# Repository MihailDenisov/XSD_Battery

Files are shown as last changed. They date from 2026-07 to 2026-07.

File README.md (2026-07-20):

# XDS_Batt — аналог аккумуляторной батареи для осциллографа Owon XDS

Плата-замена штатной аккумуляторной сборки осциллографа Owon XDS: та же механическая компоновка и электрический интерфейс (10-контактный разъём), но с ёмкостью элементов увеличенной с ~2000 до 4000 мАч (Vapcell N40), удешевлённым контроллером заряда и собственной логикой автоматического отключения выходного преобразователя во время хранения — устраняет паразитный разряд оригинальной батареи (полная разрядка за 1-1.5 месяца даже при выключенном приборе).

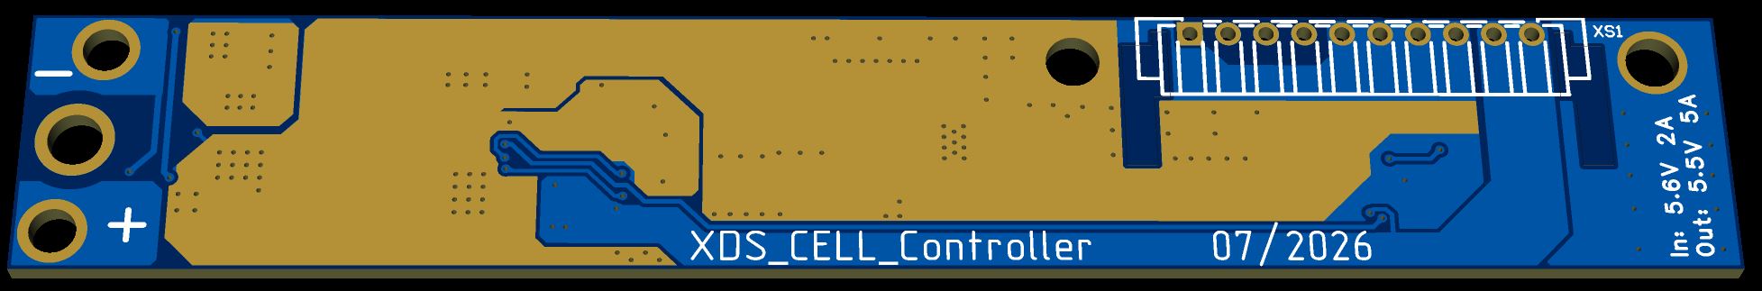
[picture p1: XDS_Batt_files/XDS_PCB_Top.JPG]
PCB top

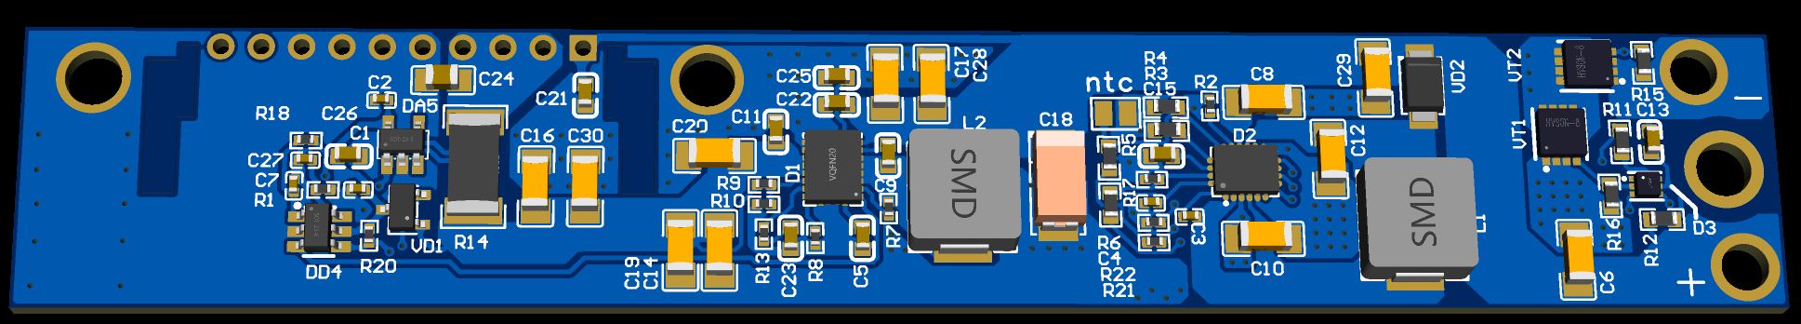
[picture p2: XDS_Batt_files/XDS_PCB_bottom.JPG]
PCB bottom


Проект платы (EasyEDA/OSHWLab): [project_svjrqlut](https://oshwlab.com/mihaildenisov/project_svjrqlut) *(ссылка станет доступна после прохождения модерации)*

Gerber-файлы для заказа платы: [XDS_Batt_Controller.zip](XDS_Batt_Controller.zip)

## Совместимость

Батарея и разъём повторяют оригинальную механику и распиновку, поэтому применимы (под одним и тем же OEM-корпусом/платформой) к следующим сериям осциллографов:

| Бренд | Серии |
|---|---|
| OWON | XDS 30xx, 31xx, 32xx, 33xx |
| АКИП | 4122/(7-12) |
| АКТАКОМ | ADS 60xx, 61xx, 62xx, 63xx |
| VERDO | SB16xx |

## Основные характеристики

| Параметр | Значение |
|---|---|
| Аккумуляторная сборка | 1S6P, Li-Ion 18650, Vapcell N40 (4000 мАч/элемент) |
| Вход заряда | 5.6 В, до 2 А |
| Выход (питание осциллографа) | 5.5 В, до 5 А |
| Автоотключение при простое | ~48 часов без нагрузки и без заряда → перевод в транспортировочный режим |
| Интерфейс | 10-контактный разъём (совместим с оригинальной батареей) |

## Архитектура платы

Полная принципиальная схема — `XDS_Batt_files/XDS_Schematic.JPG`.

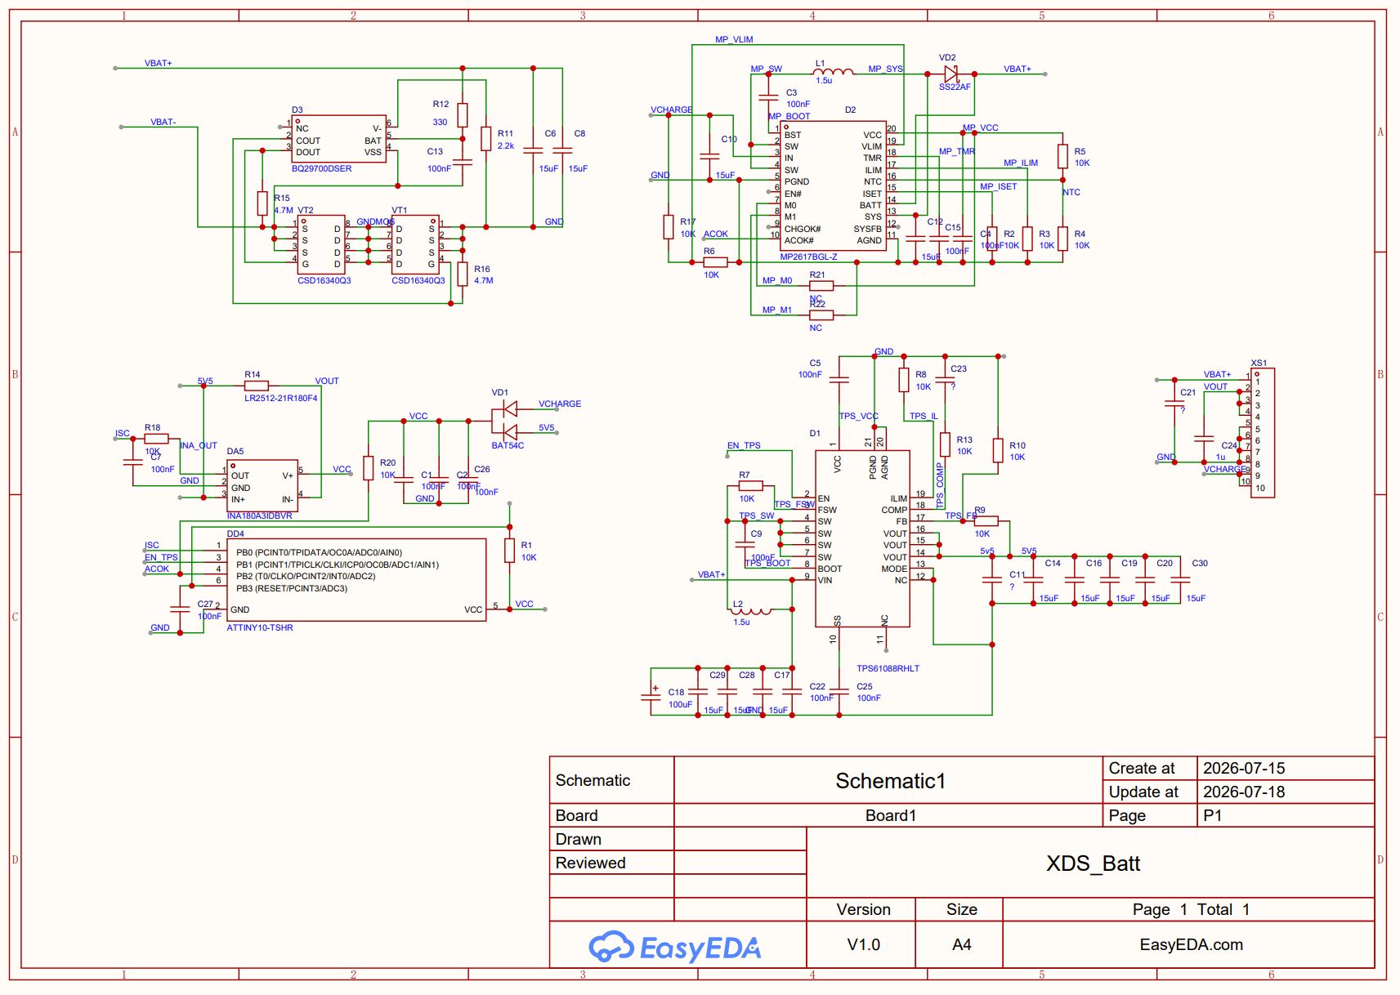
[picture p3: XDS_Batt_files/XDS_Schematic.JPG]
Schematic


### 1. Защита батареи — BQ29700 + сдвоенные N-MOSFET
Классическая схема защиты Li-Ion сборки: **BQ29700DSER** (D3) управляет двумя сдвоенными N-канальными ключами **CSD16340Q3** (VT1, VT2), включёнными последовательно в цепь VBAT- для отключения при перезаряде/переразряде/КЗ. Независима от остальной электроники платы — работает даже при полностью обесточенном контроллере.

### 2. Зарядное устройство — MP2617B
**MP2617BGL-Z** — импульсный зарядчик с автоматическим power path management:
- Входной ток ограничен ~2 А (Default Mode: M0/M1 не задействованы — R21/R22 не запаяны, что соответствует плавающим входам и заводскому лимиту тока без внешнего резистора ILIM);
- Входное напряжение ограничивается делителем на VLIM (R2-R4) — защита сетевого адаптера от просадки при перегрузке;
- Ток заряда задаётся резистором на ISET;
- Таймер безопасности — конденсатором на TMR;
- NTC-вход подключён (термоконтроль элементов при заряде);
- Статусные выходы CHGOK#/ACOK# используются платой контроллера (ACOK# — индикация наличия входного напряжения заряда для алгоритма автоотключения, см. ниже).

Выход SYS не используется как отдельная системная шина — питание повышающего преобразователя (TPS61088) берётся напрямую с VBAT+, в обход SYS, так как MP2617B не рассчитан на токи, необходимые TPS61088.

### 3. Повышающий преобразователь — TPS61088
**TPS61088RHLT** — buck-boost/boost преобразователь, формирующий выходные 5.5 В из напряжения батареи (3.0-4.2 В) для питания осциллографа. Включается/выключается по входу EN, управляемому контроллером на ATtiny10 (см. ниже) — это ключевое отличие от оригинальной батареи, где аналогичная микросхема работала постоянно и разряжала сборку даже при выключенном приборе.

### 4. Контроллер простоя — ATtiny10 + INA180A3
Узел, устраняющий паразитный разряд:

- **INA180A3IDBVR** (DA5) измеряет ток в цепи выходных 5.5 В через шунт **R14**, усиленный сигнал через RC-фильтр подаётся на вход АЦП ATtiny10 (PB0/ADC0).
- **ATtiny10** (DD4) также принимает сигнал ACOK# от зарядного устройства (PB2) и управляет входом EN преобразователя TPS61088 (PB1).
- Питание контроллера и датчика тока — через диодную сборку **BAT54C** (VD1) от входа заряда (VCHARGE) и от выхода (5V5/VOUT) — работает при наличии любого из двух источников.

**Алгоритм** (реализация — прошивка ATtiny10, Atmel Studio / avr-gcc; исходники — [ATtiny10_XDS_Power](https://github.com/MihailDenisov/XSD_Battery/tree/main/ATtiny10_XDS_Power)):
1. При появлении напряжения на входе заряда МК запускает TPS61088 (EN=1) и переходит в цикл сна с пробуждением по Watchdog каждые 8 секунд.
2. При каждом пробуждении проверяется: (а) наличие сигнала ACOK# (заряд подключён), (б) ток нагрузки выше порога (~500 мА — прибор включён).
3. Если оба условия отсутствуют — инкремент счётчика простоя; при наличии любого из них — сброс счётчика.
4. По достижении счётчиком значения, соответствующего ~48 часам непрерывного простоя, контроллер отключает TPS61088 (EN=0), обесточивая тем самым себя, датчик тока и электронику осциллографа — плата переходит в режим хранения с минимальным током утечки.
5. Выход из режима хранения — только через повторное подключение к сетевому адаптеру (появление напряжения на входе заряда).

## Разъём XS1 (совместим с оригинальной батареей)

| Контакт(ы) | Назначение |
|---|---|
| 1 | Выход для контроля уровня заряда прибором |
| 2, 3, 4 | Выход преобразователя, питание прибора 5.5 В |
| 5, 6, 7, 8 | Общий минус (GND) |
| 9, 10 | Вход от блока питания прибора для заряда |

Схема — `XDS_Batt_files/XDS_Schematic.JPG` (XS1).

## Корпус (3D-модель для печати)

Корпус состоит из двух частей: основание и крышка-слайдер (вставляется по пазам, фиксируется 1 винтом).

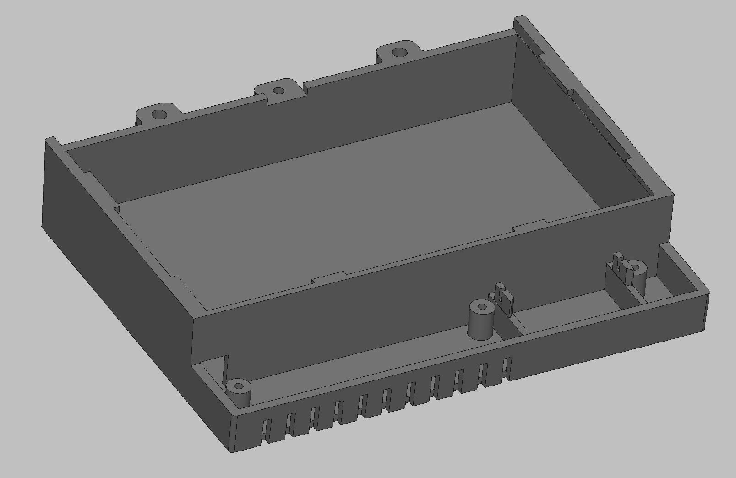
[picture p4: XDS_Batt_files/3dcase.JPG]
Основание корпуса

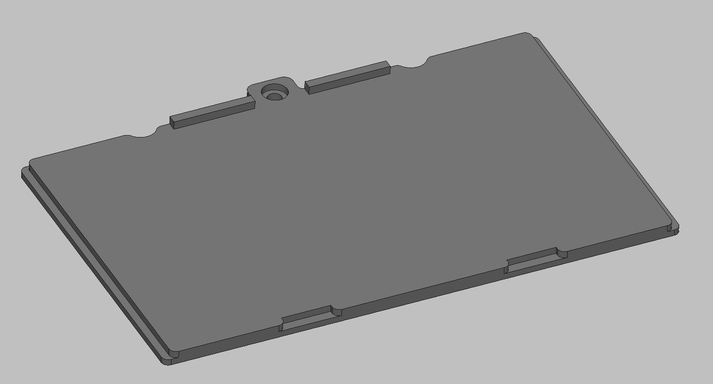
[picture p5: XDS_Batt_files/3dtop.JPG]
Крышка-слайдер


3D-модели в формате STEP:
- `Casing/xdsbattcase.stp` — основание корпуса
- `Casing/xdsbatttop.stp` — крышка-слайдер

Крепёж:
- Крышка к основанию — 1 винт.
- Плата к корпусу — 3 винта с конической шляпкой.
- Батарея (в сборе) к осциллографу — 2 винта.

Точные размеры (диаметр, длина, шаг резьбы) всех винтов будут измерены и указаны позже.

## Статус проекта / открытые вопросы

- [ ] Калибровка порога тока (500 мА) под реально измеренное потребление осциллографа во включённом/выключенном состоянии.
- [ ] Проверка активного уровня и логики ACOK# на смонтированной плате.
- [ ] Тепловые измерения MP2617B на реальном прототипе (расчётный запас по Tj при токе заряда ~2.76 А — умеренный, требует подтверждения на закрытом корпусе осциллографа).
- [ ] Финальная проверка прошивки ATtiny10 на реальном железе (в репозитории нет возможности прогнать сборку через avr-gcc/Atmel Studio при подготовке этого README).
- [ ] 3D-модель корпуса (см. раздел «Корпус» выше) — черновой вариант готов, требуется проверка посадки платы, разъёма и отверстий по месту, пробная печать.
- [ ] Схема имеет черновой вид (номиналы части компонентов не финализированы) — требуется обязательная доработка и проверка перед формированием точного BOM.

## Структура репозитория

```
/XDS_Batt_files/              — изображения платы, схемы и корпуса (используются в этом README)
  XDS_PCB_Top.JPG
  XDS_PCB_bottom.JPG
  XDS_Schematic.JPG
  3dcase.jpg
  3dtop.jpg
/ATtiny10_XDS_Power/          — прошивка ATtiny10 (Atmel Studio / avr-gcc проект)
/Casing/                      — 3D-модели корпуса (STEP)
  xdsbattcase.stp
  xdsbatttop.stp
XDS_Batt_Controller.zip       — Gerber-файлы платы
README.md
```

Исходники прошивки: [ATtiny10_XDS_Power](https://github.com/MihailDenisov/XSD_Battery/tree/main/ATtiny10_XDS_Power)

## Предупреждение по технике безопасности

Проект связан с разработкой платы заряда/защиты Li-Ion аккумуляторной сборки большой ёмкости (~86 Вт·ч). Любые изменения номиналов, схемотехники защиты (BQ29700) или зарядного тракта должны проверяться пересчётом и тестироваться с осторожностью (ограничение тока на первом включении, термоконтроль, изолированная зона тестирования). Автор(ы) не несут ответственности за повреждение оборудования или травмы при повторении конструкции.

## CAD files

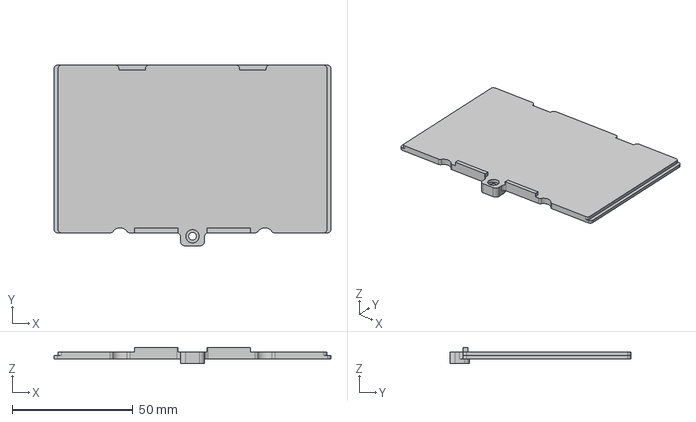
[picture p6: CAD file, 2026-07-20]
Casing/xdsbatttop.stp
114.7 x 74.9 x 6.80 mm

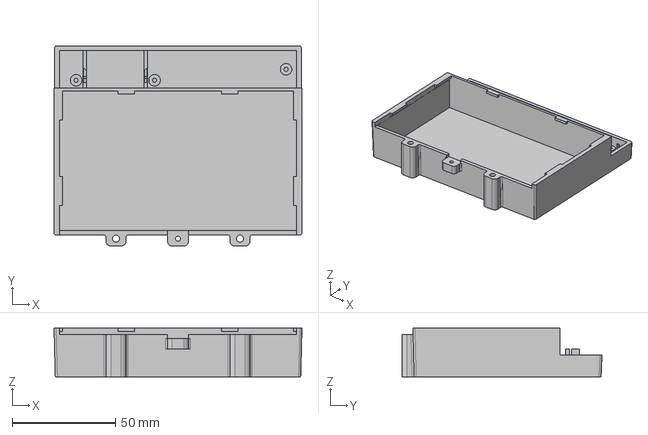
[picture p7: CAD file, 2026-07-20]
Casing/xdsbattcase.stp
120.0 x 96.9 x 23.5 mm

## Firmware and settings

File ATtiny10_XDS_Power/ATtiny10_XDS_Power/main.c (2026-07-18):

/*
 * ATtiny10 - контроллер отключения TPS61088 при простое батареи Owon XDS
 *
 * Пины (PB3/RESET намеренно не используется - фьюз RSTDISBL не программирован,
 * перевод в GPIO потребовал бы HV-программатора):
 *   PB0 - выход, EN на TPS61088 (1 = повышающий преобразователь включен)
 *   PB1 - вход,  ACOK с MP2617B (уточнить активный уровень! ниже принят активный LOW,
 *                как это типично для открытого стока у большинства зарядных ИМС)
 *   PB2 - аналоговый вход ADC2, выход INA180A3 (пропорционален выходному току)
 *
 * ВАЖНО перед прошивкой:
 *   1) Проверить реальный порог CUR_THRESHOLD_ADC под ваш шунт/усиление
 *      (см. расчёт в комментарии ниже).
 *   2) Проверить активный уровень ACOK по даташиту конкретной ревизии MP2617B
 *      и, если нужно, поменять логику в charger_present().
 *   3) Если ACOK - выход с открытым стоком, обязательно включить подтяжку PUEB1
 *      (сделано ниже) либо поставить внешний резистор.
 */

#define F_CPU 1000000UL   /* внутренний RC 8МГц / 8 (CLKPSR сброс = /8) - фьюзы не трогаем */

#include <avr/io.h>
#include <avr/interrupt.h>
#include <avr/sleep.h>

/*
 * ATtiny10 не имеет единого именования битов вида PB0/PB1 - в iotn10.h
 * у каждого регистра свой набор (DDB0.., PORTB0.., PINB0.., PUEB0..),
 * но номер бита совпадает с физическим номером вывода для всех них,
 * поэтому используем простые числовые константы.
 */
#define EN_TPS_BIT     0   /* PB0: выход -> EN на TPS61088 */
#define ACOK_BIT       1   /* PB1: вход  <- ACOK с MP2617B */
#define ISENSE_ADC_CH  2   /* PB2 = ADC2, см. ADMUX MUX[1:0] в iotn10.h */

/* ---- Пороги алгоритма ---- */
/*
 * ВАЖНО: АЦП у ATtiny4/5/9/10 - 8-БИТНЫЙ (регистр ADCL, без ADCH),
 * опорное напряжение фиксировано на Vcc (REFS-битов в ADMUX нет).
 * Порог тока ~500 мА. Пример расчёта под INA180A3 (Gain = 100 В/В):
 *   R_shunt = 0.020 Ом  ->  V_shunt(0.5А) = 0.5 * 0.02 = 10 мВ
 *   V_out(INA180) = 10 мВ * 100 = 1.0 В
 *   код АЦП (8 бит, Vref = Vcc ~= 5.0В) = 1.0В / 5.0В * 255 ~= 51
 * ЗАГЛУШКА - обязательно пересчитать под фактический шунт и реально измеренный
 * ток прибора во "выключенном" состоянии (с запасом от него). При 8-битном
 * АЦП разрешение грубее, чем на классических AVR - учтите это при выборе
 * шунта/усиления, чтобы порог не "терялся" в 1-2 младших битах.
 */
#define CUR_THRESHOLD_ADC   51U

#define IDLE_LIMIT_TICKS    21600UL  /* ~48ч при шаге WDT 8с (48*3600/8=21600, влезает в uint16_t) */
#define SAMPLES_PER_WAKE    4        /* усреднение отсчётов АЦП на одном пробуждении */

#define CCP_SIGNATURE        0xD8   /* Table 5-2: signature for CLKMSR/CLKPSR/WDTCSR */

static volatile uint16_t idle_counter = 0;

/* ---------- ADC ---------- */
static void adc_init(void)
{
    ADMUX = ISENSE_ADC_CH;                  /* канал ADC2 (PB2) */
    ADCSRA = (1 << ADPS1) | (1 << ADPS0);   /* делитель тактовой АЦП */
    DIDR0 |= (1 << ADC2D);                  /* выключить цифровой буфер на PB2 - меньше ток, нет помех АЦП */
}

static uint8_t adc_read_avg(void)
{
    /* ADCL - единственный регистр данных АЦП на этом чипе (8 бит, без ADCH) */
    uint16_t acc = 0; /* max 4 * 255 = 1020, помещается в uint16_t */

    ADCSRA |= (1 << ADEN);
    for (volatile uint16_t d = 0; d < 200; d++) { /* время установления после включения АЦП */
    }

    for (uint8_t i = 0; i < SAMPLES_PER_WAKE; i++) {
        ADCSRA |= (1 << ADSC);
        while (ADCSRA & (1 << ADSC)) {
        }
        acc += ADCL;
    }

    ADCSRA &= ~(1 << ADEN); /* выключаем АЦП обратно перед сном - экономия тока */
    return (uint8_t)(acc / SAMPLES_PER_WAKE);
}

/* ---------- WDT: настройка Interrupt Mode на 8с через защищённую запись CCP ---------- */
static void wdt_init_interrupt_8s(void)
{
    cli();
    /* Защищённая запись WDTCSR: сигнатура CCP и запись в течение 4 тактов.
       Пишем их подряд без вызовов функций между ними, чтобы гарантировать тайминг. */
    CCP = CCP_SIGNATURE;
    WDTCSR = (1 << WDIE) | (1 << WDP3) | (1 << WDP0); /* WDE=0 -> чистый Interrupt Mode, 8.0с */
    sei();
}

ISR(WDT_vect)
{
    /* WDIF аппаратно очищается при входе в вектор; WDIE в чистом Interrupt Mode
       (WDE=0) НЕ сбрасывается автоматически - повторно взводить не нужно.
       Тело пустое: вся логика - в главном цикле после пробуждения. */
}

static inline uint8_t charger_present(void)
{
    /* ПРИНЯТО: ACOK активен низким уровнем (открытый сток, типично для зарядных ИМС).
       ПРОВЕРИТЬ по даташиту конкретной ревизии MP2617B и поменять при необходимости. */
    return (PINB & (1 << ACOK_BIT)) ? 0 : 1;
}

int main(void)
{
    /* Настройка выводов */
    DDRB |= (1 << EN_TPS_BIT);      /* EN - выход */
    DDRB &= ~(1 << ACOK_BIT);       /* ACOK - вход */

    /* Если ACOK на MP2617B - открытый сток, нужна подтяжка (на ATtiny10 подтяжка
       управляется регистром PUEB, а не PORTB, как на классических AVR) */
    PUEB |= (1 << ACOK_BIT);

    PORTB &= ~(1 << EN_TPS_BIT);    /* гарантированно выключен до осознанного включения */

    /* Явный пуск TPS61088 после инициализации прошивки */
    PORTB |= (1 << EN_TPS_BIT);

    adc_init();
    wdt_init_interrupt_8s();
    set_sleep_mode(SLEEP_MODE_PWR_DOWN);

    while (1) {
        sleep_enable();
        sleep_cpu();
        sleep_disable();

        uint8_t cur = adc_read_avg();
        uint8_t chg  = charger_present();

        if (chg || (cur > CUR_THRESHOLD_ADC)) {
            idle_counter = 0;
        } else {
            if (idle_counter < IDLE_LIMIT_TICKS) {
                idle_counter++;
            }
            if (idle_counter >= IDLE_LIMIT_TICKS) {
                PORTB &= ~(1 << EN_TPS_BIT); /* выключаем TPS61088 */
                /* Если заряд отсутствует, контроллер сам обесточится через
                   диодное ИЛИ от выхода 5.5В. Ниже - страховка на случай,
                   если по какой-то причине питание ещё есть. */
                cli();
                while (1) {
                    sleep_enable();
                    sleep_cpu();
                }
            }
        }
    }
}
